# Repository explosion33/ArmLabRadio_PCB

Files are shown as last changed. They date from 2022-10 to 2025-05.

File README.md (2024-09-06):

# ArmLabRadio_PCB
KiCad files for CC1200 and STM32 based 2m / 70cm radio

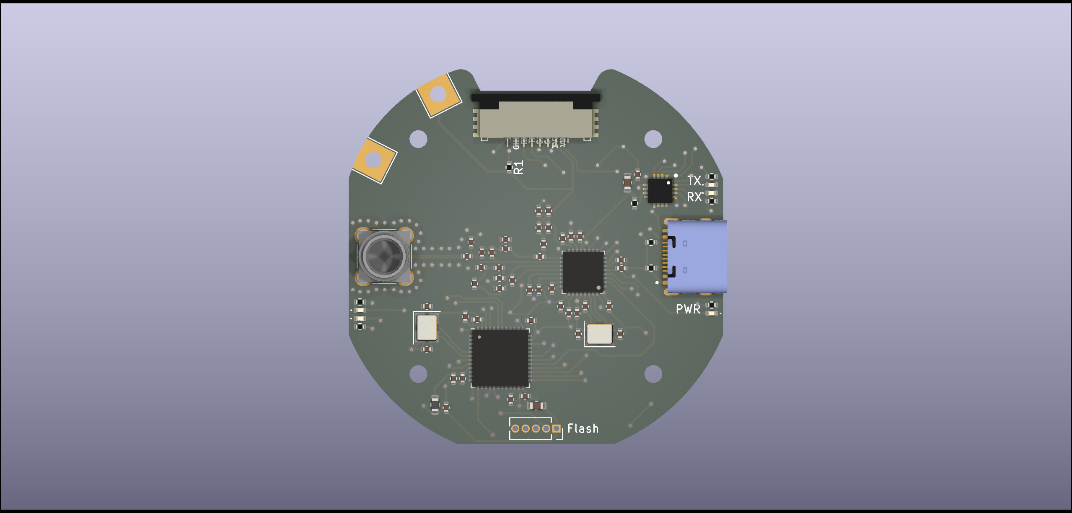
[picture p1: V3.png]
v3


## Software
This is the hardware repo for the project, checkout

[CC1200stm32](https://github.com/explosion33/CC1200stm32) for the embedded device code

[ArmLabCC1200](https://github.com/explosion33/ArmLabCC1200) for Serial / I2C inteface libraries

## Other
checkout

[RGRadioAPI](https://github.com/explosion33/RGRadioApi) for an example use case

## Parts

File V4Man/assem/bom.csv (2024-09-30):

Comment | Designator | Footprint | LCSC Part #
4.7uF Unpolarized capacitor | C1 | C_0603_1608Metric | C71631
10uF Unpolarized capacitor | C2 | C_0603_1608Metric | c
10pF Unpolarized capacitor | C3,C6,C31,C36 | C_0402_1005Metric | C32949
100nF Unpolarized capacitor | C4,C5,C7,C8,C13 | C_0402_1005Metric | C307331
2.2uF Unpolarized capacitor | C9 | C_0402_1005Metric | C12530
10nF Unpolarized capacitor | C10,C14,C20,C22,C42 | C_0402_1005Metric | C15195
1uF Unpolarized capacitor | C11,C12,C40 | C_0402_1005Metric | C52923
47nF Unpolarized capacitor | C15,C17,C18,C19,C23,C24,C25,C28,C29 | C_0402_1005Metric | C508865
0.22 uF Unpolarized capacitor | C16 | C_0402_1005Metric | C16772
1.8nF Unpolarized capacitor | C21 | C_0402_1005Metric | C162192
56pF Unpolarized capacitor | C26 | C_0402_1005Metric | C335543
100pF Unpolarized capacitor | C27 | C_0402_1005Metric | C126492
39pF Unpolarized capacitor | C30 | C_0402_1005Metric | C86288
5.1pF Unpolarized capacitor | C32,C33,C35 | C_0402_1005Metric | C281761
2.2pF Unpolarized capacitor | C34 | C_0402_1005Metric | C159806
6.2pF Unpolarized capacitor | C37 | C_0402_1005Metric | C325456
220pF Unpolarized capacitor | C38,C39 | C_0402_1005Metric | C363516
1nF Unpolarized capacitor | C41 | C_0402_1005Metric | C189467
220uF Unpolarized capacitor | C43 | C_1206_3216Metric | C528968
10uF Unpolarized capacitor | C44 | C_0402_1005Metric | C52923
100uF Unpolarized capacitor | C45 | C_0805_2012Metric | C141660
330uF Unpolarized capacitor | C46 | CP_Elec_10x10.5 | C5162354
22uF Unpolarized capacitor | C47,C48 | C_0805_2012Metric | C5674
PWR_LED Light emitting diode | D1 | LED_0402_1005Metric | C5160717
LED Light emitting diode | D2,D3 | LED_0402_1005Metric | C130722
TXT Light emitting diode | D4 | LED_0402_1005Metric | C136765
RXT Light emitting diode | D5 | LED_0402_1005Metric | C130722
SS34 40V 3A Schottky Diode, SMA | D6 | D_SMA | C3032484
EXT1 Generic connector, single row, 01x08, script generated (kicad-library-utils/schlib/autogen/connector/) | EX1 | Molex_200528-0080_1x08-1MP_P1.00mm_Horizontal | C132510
120R Ferrite bead, small symbol | FB1 | L_0603_1608Metric | C85831
MountingHole Mounting Hole without connection | H1,H2,H3,H4 | MountingHole_2.2mm_M2
TYPE-C-31-M-12 | J1 | HRO_TYPE-C-31-M-12 | C165948
PWR Generic connector, single row, 01x01, script generated (kicad-library-utils/schlib/autogen/connector/) | J2,J4 | TestPoint_THTPad_4.0x4.0mm_Drill2.0mm
GND Generic connector, single row, 01x01, script generated (kicad-library-utils/schlib/autogen/connector/) | J3,J5 | TestPoint_THTPad_4.0x4.0mm_Drill2.0mm
Conn_01x03_Pin Generic connector, single row, 01x03, script generated | J6 | PinHeader_1x03_P2.54mm_Vertical
56nH Inductor symbol for simulation only | L1,L2 | C_0402_1005Metric | C167484
27nH Inductor symbol for simulation only | L3,L4 | C_0402_1005Metric | C12669
15nH Inductor symbol for simulation only | L5,L6 | C_0402_1005Metric | C27143
22nH Inductor symbol for simulation only | L7 | C_0402_1005Metric | C12670
220uH Inductor | L8 | L_Sunlord_SWRB1207S | C182174
AntMount Generic connector, single row, 01x01, script generated (kicad-library-utils/schlib/autogen/connector/) | P1 | SMA_Amphenol_132134-11_Vertical | C504007
5.11k Resistor | R1,R3,R4,R12 | R_0402_1005Metric | C25906
0 Resistor, small US symbol | R2 | C_0402_1005Metric | C138289
1k Resistor | R5,R6,R7,R10,R11,R14,R15,R18 | R_0402_1005Metric | C11702
56k Resistor, small US symbol | R8 | C_0402_1005Metric | C25796
18k Resistor, small US symbol | R9 | C_0402_1005Metric | C25084
0R Resistor, small US symbol | R13 | C_0402_1005Metric | C138289
1.8k Resistor | R16 | R_0402_1005Metric | C170383
3.9k Resistor | R17 | R_0402_1005Metric | C413091
FLASH Generic connector, single row, 01x06, script generated (kicad-library-utils/schlib/autogen/connector/) | SWD1 | PinSocket_1x05_P2.54mm_Vertical
STM32F401CCU6 ARM Cortex-M4 MCU, 256KB flash, 64KB RAM, 84MHz, 1.7-3.6V, 36 GPIO, UFQFPN-48 | U1 | QFN-48-1EP_7x7mm_P0.5mm_EP5.6x5.6mm | C79861
CP2102N-Axx-xQFN20 USB to UART master bridge, QFN-20 | U2 | WFQFN-20 | C969913
CC1200 Low-Power, High-Performance RF Transceiver, QFN-32 | U3 | QFN-32-1EP_5x5mm_P0.5mm_EP3.45x3.45mm | C122881
SKY65366-21 | U4 | SKY65366-21_SKY
LM2576S 3.3V, 3A SIMPLE SWITCHER® Step-Down Voltage Regulator, TO-263 | U5 | TO-263-5_TabPin3 | C347415
AMS1117-3.3 1A Low Dropout regulator, positive, 3.3V fixed output, SOT-223 | U6 | SOT-223-3_TabPin2 | C6186
40MHz Four pin crystal, GND on pins 2 and 4 | X1 | Oscillator_SMD_Abracon_ASE-4Pin_3.2x2.5mm | C9010
16MHz Four pin crystal, GND on pins 2 and 4 | Y1 | Crystal_SMD_3225-4Pin_3.2x2.5mm | C13738

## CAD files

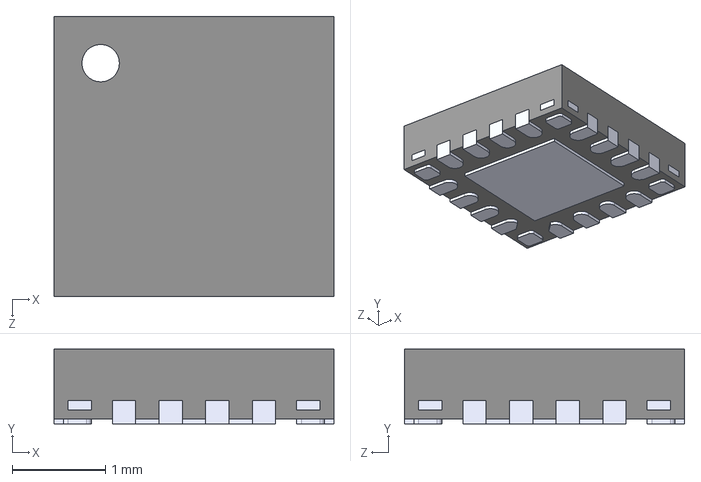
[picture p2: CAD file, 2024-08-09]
CP2102/CP2102N-A02-GQFN20.step
3.00 x 0.8 x 3.00 mm

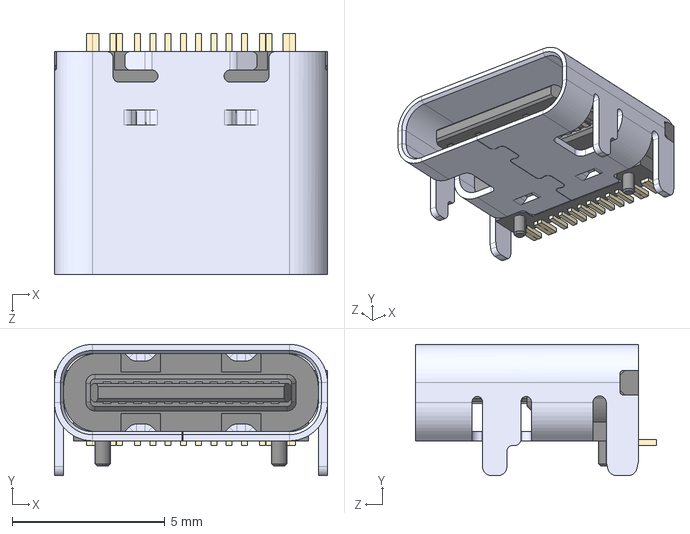
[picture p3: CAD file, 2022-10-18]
usbc/TYPE-C-31-M-12.step
8.94 x 4.30 x 7.90 mm

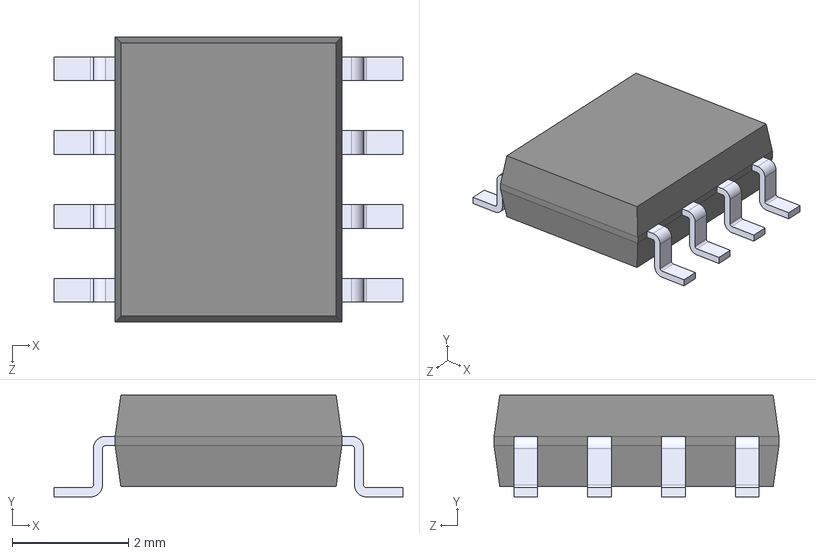
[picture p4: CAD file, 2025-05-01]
MCP41010/MCP41010-I_SN.step
6.00 x 1.75 x 4.90 mm

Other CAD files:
CP2102/cp2102n-a02-gqfn20.obj

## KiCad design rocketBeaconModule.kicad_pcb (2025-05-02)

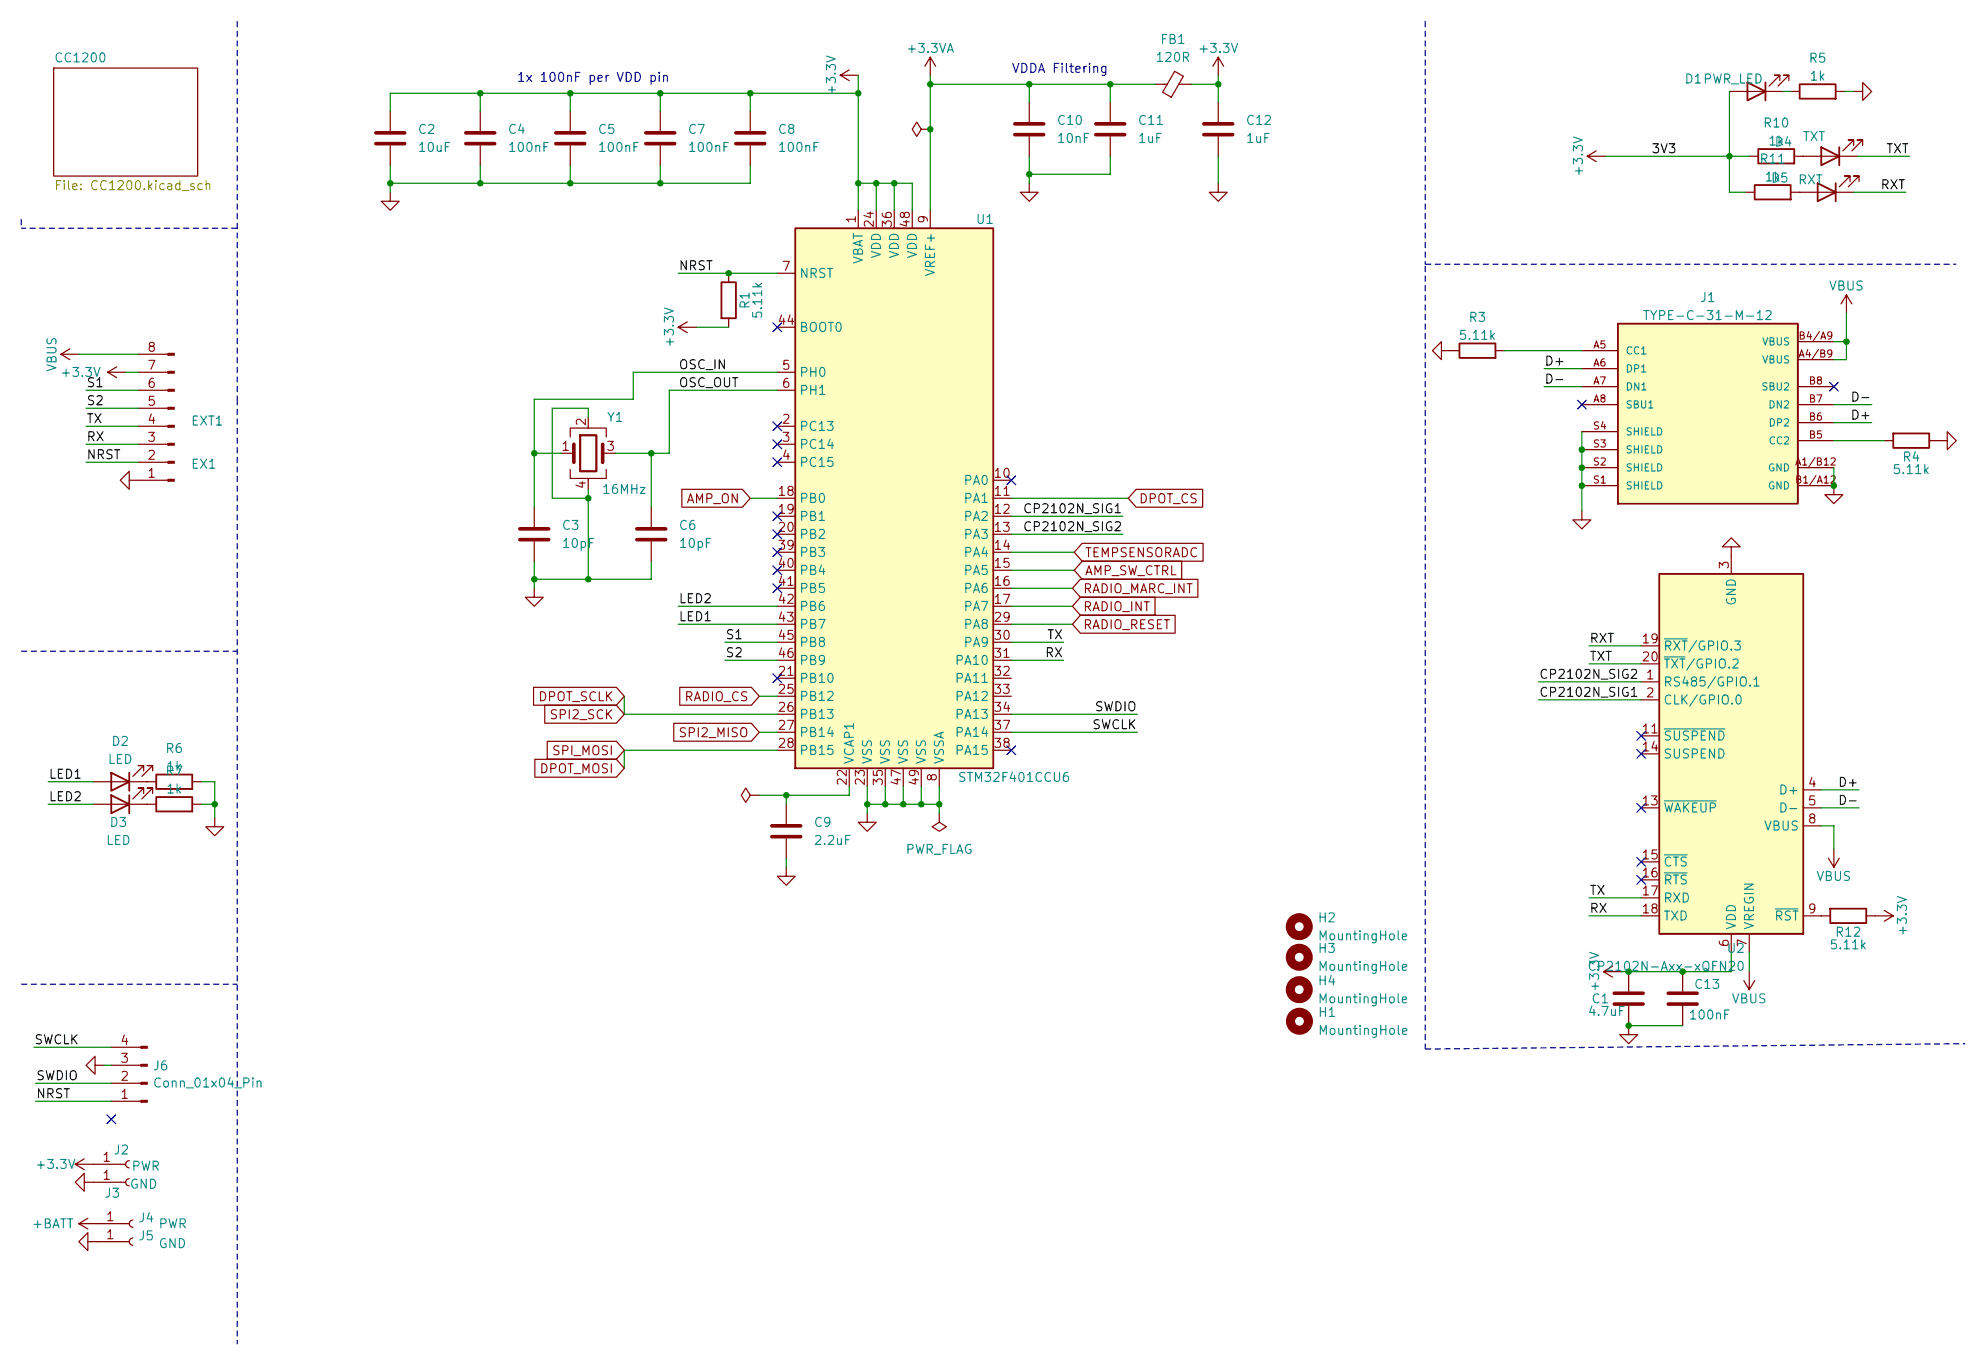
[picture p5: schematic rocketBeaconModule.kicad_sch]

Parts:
C1: 4.7uF; C_0603_1608Metric; LCSC Part C71631
C2: 10uF; C_0603_1608Metric; LCSC Part C19702
C3, C6: 10pF; C_0402_1005Metric; LCSC Part C32949
C4, C5, C7, C8, C13: 100nF; C_0402_1005Metric; LCSC Part C307331
C9: 2.2uF; C_0402_1005Metric; LCSC Part C12530
C10: 10nF; C_0402_1005Metric; LCSC Part C15195
C11, C12: 1uF; C_0402_1005Metric; LCSC Part C52923
D1: PWR_LED; LED_0402_1005Metric; LCSC Part C5160717
D2: LED; LED_0402_1005Metric; LCSC Part C131223
D3: LED; LED_0402_1005Metric; LCSC Part C130722
D4: TXT; LED_0402_1005Metric; LCSC Part C136765
D5: RXT; LED_0402_1005Metric; LCSC Part C130722
EX1: EXT1; Molex_200528-0080_1x08-1MP_P1.00mm_Horizontal; LCSC Part C132510
FB1: 120R; L_0603_1608Metric; LCSC Part C85831
H1, H2, H3, H4: MountingHole; MountingHole_2.2mm_M2
J1: TYPE-C-31-M-12; HRO_TYPE-C-31-M-12; PARTREV 2020.12.08; LCSC Part C165948
J2, J4: PWR; TestPoint_THTPad_4.0x4.0mm_Drill2.0mm
J3, J5: GND; TestPoint_THTPad_4.0x4.0mm_Drill2.0mm
J6: Conn_01x04_Pin; PinHeader_1x04_P2.54mm_Vertical
R1, R3, R4, R12: 5.11k; R_0402_1005Metric; LCSC Part C25906
R5, R6, R7, R10, R11: 1k; R_0402_1005Metric; LCSC Part C11702
U1: STM32F401CCU6; QFN-48-1EP_7x7mm_P0.5mm_EP5.6x5.6mm; LCSC Part C79861
U2: CP2102N-Axx-xQFN20; WFQFN-20; LCSC Part C969913
Y1: 16MHz; Crystal_SMD_3225-4Pin_3.2x2.5mm; LCSC Part C13738

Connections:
+3.3V: C1.1, C2.1, C4.1, C5.1, C7.1, C8.1, C12.1, C13.1, D1.2 (A), EX1.7, FB1.2, J2.1, R1.2, R10.1, R11.1, R12.1, U1.1 (VBAT), U1.24 (VDD), U1.36 (VDD), U1.48 (VDD), U2.6 (VDD); also elsewhere on the board
+3.3VA: C10.1, C11.1, FB1.1, U1.9 (VREF+)
+BATT: J4.1; also elsewhere on the board
/CP2102N_SIG1: U1.12 (PA2), U2.2 (CLK/GPIO.0)
/CP2102N_SIG2: U1.13 (PA3), U2.1 (RS485/GPIO.1)
/D+: J1.A6 (DP1), J1.B6 (DP2), U2.4 (D+)
/D-: J1.A7 (DN1), J1.B7 (DN2), U2.5 (D-)
/LED1: D2.2 (A), U1.43 (PB7)
/LED2: D3.2 (A), U1.42 (PB6)
/NRST: EX1.2, J6.1, R1.1, U1.7 (NRST)
/OSC_IN: C3.1, U1.5 (PH0), Y1.1
/OSC_OUT: C6.1, U1.6 (PH1), Y1.3
/RX: EX1.3, U1.31 (PA10), U2.18 (TXD)
/RXT: D5.1 (K), U2.19 (~RXT/GPIO.3)
/S1: EX1.6, U1.45 (PB8)
/S2: EX1.5, U1.46 (PB9)
/SWCLK: J6.4, U1.37 (PA14)
/SWDIO: J6.2, U1.34 (PA13)
/TX: EX1.4, U1.30 (PA9), U2.17 (RXD)
/TXT: D4.1 (K), U2.20 (~TXT/GPIO.2)
AMP_ON: U1.18 (PB0); also elsewhere on the board
AMP_SW_CTRL: U1.15 (PA5); also elsewhere on the board
DPOT_CS: U1.11 (PA1); also elsewhere on the board
DPOT_MOSI: U1.28 (PB15); also elsewhere on the board
DPOT_SCLK: U1.26 (PB13); also elsewhere on the board
GND: C1.2, C2.2, C3.2, C4.2, C5.2, C6.2, C7.2, C8.2, C9.2, C10.2, C11.2, C12.2, C13.2, EX1.1, J1.A1/B12 (GND), J1.B1/A12 (GND), J1.S1 (SHIELD), J1.S2 (SHIELD), J1.S3 (SHIELD), J1.S4 (SHIELD), J3.1, J5.1, J6.3, R3.1, R4.1, R5.2, R6.2, R7.2, U1.8 (VSSA), U1.23 (VSS), U1.35 (VSS), U1.47 (VSS), U1.49 (VSS), U2.3 (GND), U2.12 (GND), Y1.2, Y1.4; also elsewhere on the board
unnamed: D1.1 (K), R5.1
unnamed: D2.1 (K), R6.1
unnamed: D3.1 (K), R7.1
unnamed: D4.2 (A), R10.2
unnamed: D5.2 (A), R11.2
unnamed: J1.A5 (CC1), R3.2
unnamed: J1.B5 (CC2), R4.2
unnamed: C9.1, U1.22 (VCAP1)
unnamed: R12.2, U2.9 (~RST)
RADIO_CS: U1.25 (PB12); also elsewhere on the board
RADIO_INT: U1.17 (PA7); also elsewhere on the board
RADIO_MARC_INT: U1.16 (PA6); also elsewhere on the board
RADIO_RESET: U1.29 (PA8); also elsewhere on the board
SPI2_MISO: U1.27 (PB14); also elsewhere on the board
TEMPSENSORADC: U1.14 (PA4); also elsewhere on the board
VBUS: EX1.8, J1.A4/B9 (VBUS), J1.B4/A9 (VBUS), U2.7 (VREGIN), U2.8 (VBUS)

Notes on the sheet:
VDDA Filtering
1x 100nF per VDD pin

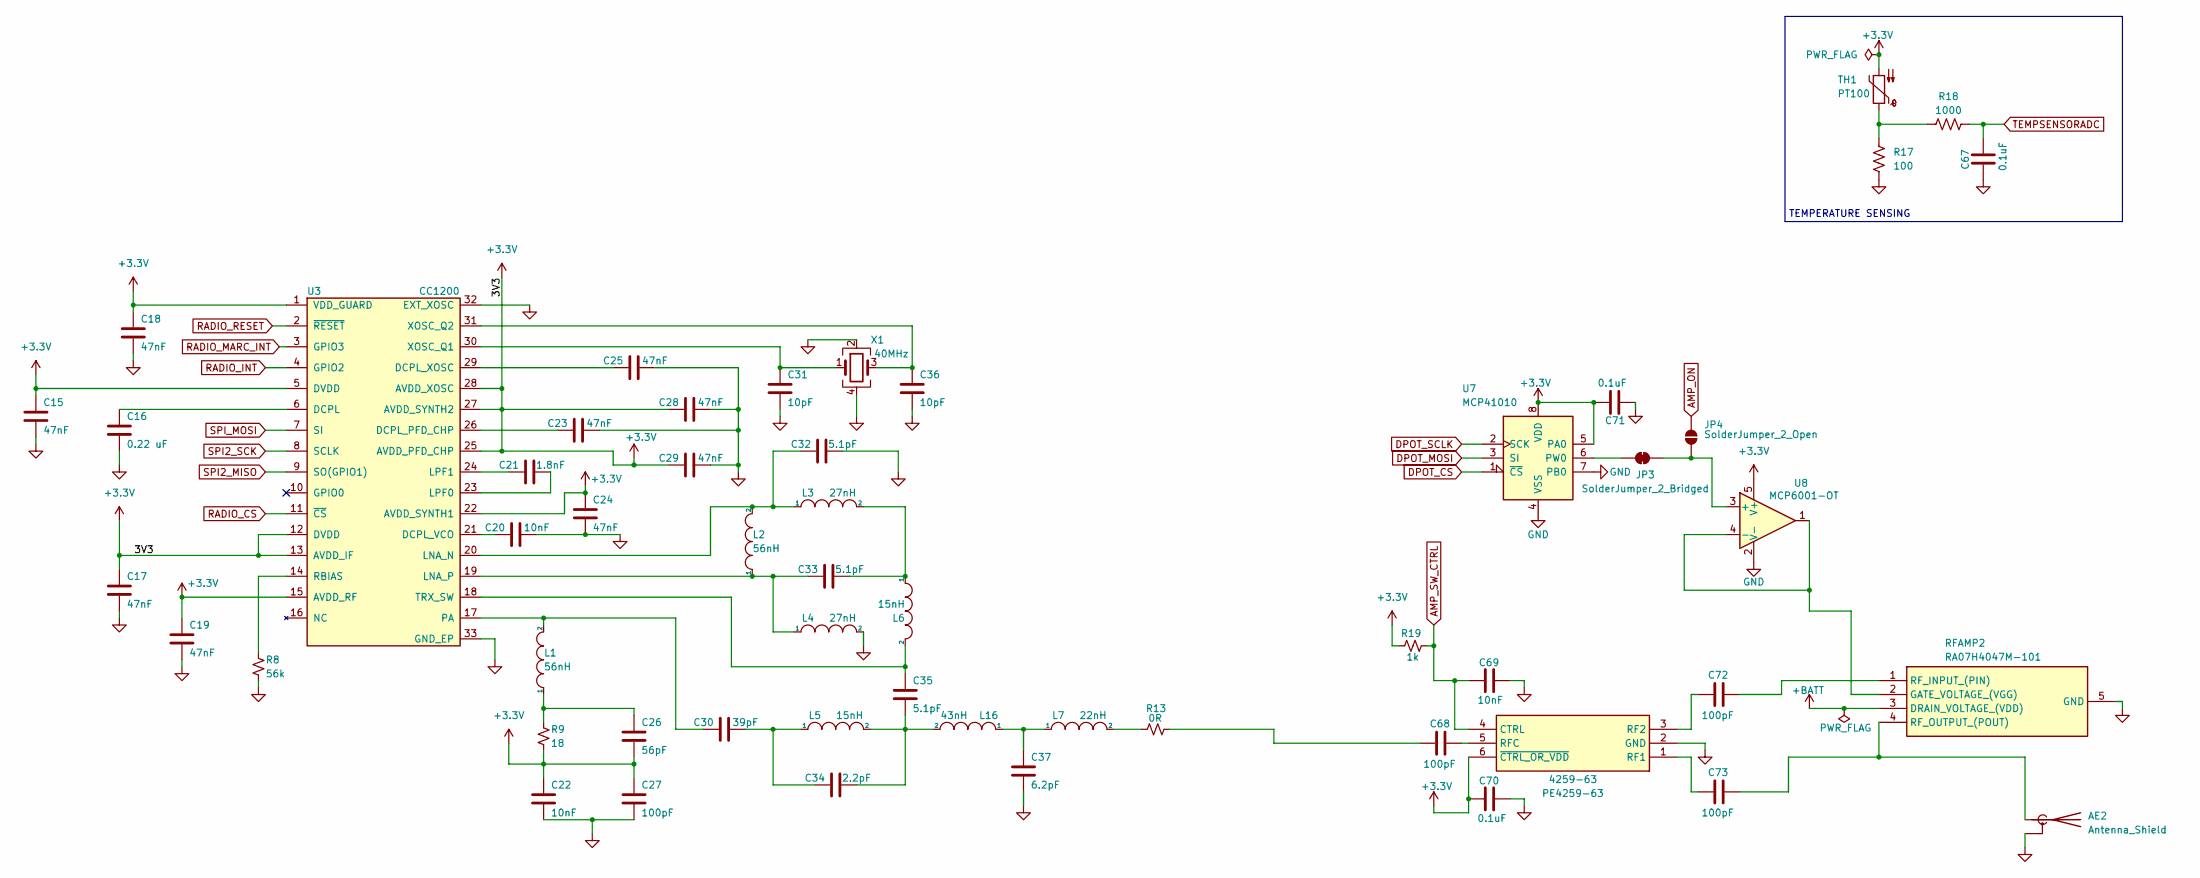
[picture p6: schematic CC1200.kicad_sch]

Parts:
AE2: Antenna_Shield; SMA_Amphenol_132134-11_Vertical; LCSC Part C496549
C15, C17, C18, C19, C23, C24, C25, C28, C29: 47nF; C_0402_1005Metric; LCSC Part C508865
C16: 0.22 uF; C_0402_1005Metric; LCSC Part C16772
C20, C22: 10nF; C_0402_1005Metric; LCSC Part C15195
C21: 1.8nF; C_0402_1005Metric; LCSC Part C162192
C26: 56pF; C_0402_1005Metric; LCSC Part C335543
C27: 100pF; C_0402_1005Metric; LCSC Part C126492
C30: 39pF; C_0402_1005Metric; LCSC Part C86288
C31, C36: 10pF; C_0402_1005Metric; LCSC Part C32949
C32, C33, C35: 5.1pF; C_0402_1005Metric; LCSC Part C281761
C34: 2.2pF; C_0402_1005Metric; LCSC Part C159806
C37: 6.2pF; C_0402_1005Metric; LCSC Part C325456
C67, C71: 0.1uF; C_0402_1005Metric; LCSC Part C1525
C68, C72, C73: 100pF; C_0402_1005Metric; LCSC C1546
C69: 10nF; C_0402_1005Metric; LCSC C15195
C70: 0.1uF; C_0402_1005Metric; LCSC C1525
JP3: SolderJumper_2_Bridged; SolderJumper-2_P1.3mm_Bridged_RoundedPad1.0x1.5mm
JP4: SolderJumper_2_Open; SolderJumper-2_P1.3mm_Open_RoundedPad1.0x1.5mm
L1, L2: 56nH; C_0402_1005Metric; LCSC Part C167484
L3, L4: 27nH; C_0402_1005Metric; LCSC Part C12669
L5, L6: 15nH; C_0402_1005Metric; LCSC Part C27143
L7: 22nH; C_0402_1005Metric; LCSC Part C12670
L16: 43nH; L_0402_1005Metric; LCSC Part C167478
PE4259-63: 4259-63; SOT-363_SC-70-6; Manufacturer_Part_Number 4259-63; LCSC Part C470892
R8: 56k; C_0402_1005Metric; LCSC Part C25796
R9: 18; R_0402_1005Metric; LCSC Part C25084
R13: 0R; C_0402_1005Metric; LCSC Part C138289
R17: 100; R_0402_1005Metric; LCSC Part C25076
R18: 1000; R_0402_1005Metric; LCSC Part C21190
R19: 1k; R_0402_1005Metric; LCSC C11702
RFAMP2: RA07H4047M-101; RA07h4047M; Manufacturer_Part_Number RA07H4047M-101
TH1: PT100; R_0603_1608Metric; LCSC Part C141518
U3: CC1200; QFN-32-1EP_5x5mm_P0.5mm_EP3.45x3.45mm; LCSC Part C122881
U7: MCP41010; SOIC127P599X175-8N; LCSC Part C136395
U8: MCP6001-OT; SOT-23-5; LCSC Part C116490
X1: 40MHz; Oscillator_SMD_Abracon_ASE-4Pin_3.2x2.5mm; LCSC Part C9010

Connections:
+3.3V: C15.1, C17.1, C18.1, C19.1, C22.1, C24.1, C26.2, C27.1, C28.2, C29.2, C70.2, C71.1, PE4259-63.6 (~CTRL_OR_VDD), R9.2, R19.2, TH1.2, U3.1 (VDD_GUARD), U3.5 (DVDD), U3.12 (DVDD), U3.13 (AVDD_IF), U3.15 (AVDD_RF), U3.22 (AVDD_SYNTH1), U3.25 (AVDD_PFD_CHP), U3.27 (AVDD_SYNTH2), U3.28 (AVDD_XOSC), U7.5 (PA0), U7.8 (VDD), U8.5 (V+); also elsewhere on the board
+BATT: RFAMP2.3 (DRAIN_VOLTAGE_(VDD)); also elsewhere on the board
AMP_ON: JP4.2 (B); also elsewhere on the board
AMP_SW_CTRL: C69.2, PE4259-63.4 (CTRL), R19.1; also elsewhere on the board
DPOT_CS: U7.1 (~CS); also elsewhere on the board
DPOT_MOSI: U3.7 (SI), U7.3 (SI); also elsewhere on the board
DPOT_SCLK: U3.8 (SCLK), U7.2 (SCK); also elsewhere on the board
GND: AE2.2 (Shield), C15.2, C16.2, C17.2, C18.2, C19.2, C20.1, C22.2, C23.1, C24.2, C25.1, C27.2, C28.1, C29.1, C31.2, C32.1, C36.2, C37.2, C67.2, C69.1, C70.1, C71.2, L4.2, PE4259-63.2 (GND), R8.2, R17.2, RFAMP2.5 (GND), U3.32 (EXT_XOSC), U3.33 (GND_EP), U7.4 (VSS), U7.7 (PB0), U8.2 (V-), X1.2, X1.4; also elsewhere on the board
unnamed: AE2.1 (A), C73.2, RFAMP2.4 (RF_OUTPUT_(POUT))
unnamed: C26.1, L1.1, R9.1
unnamed: C30.1, C34.2, L5.1
unnamed: C33.1, L3.2, L6.1
unnamed: C34.1, C35.2, L5.2, L16.2
unnamed: C37.1, L7.1, L16.1
unnamed: C68.1, R13.2
unnamed: JP3.1 (A), U7.6 (PW0)
unnamed: JP3.2 (B), JP4.1 (A), U8.3 (+)
unnamed: L7.2, R13.1
unnamed: C73.1, PE4259-63.1 (RF1)
unnamed: C72.1, PE4259-63.3 (RF2)
unnamed: C68.2, PE4259-63.5 (RFC)
unnamed: R17.1, R18.1, TH1.1
unnamed: RFAMP2.2 (GATE_VOLTAGE_(VGG)), U8.1, U8.4 (-)
unnamed: C72.2, RFAMP2.1 (RF_INPUT_(PIN))
unnamed: C16.1, U3.6 (DCPL)
unnamed: C23.2, U3.26 (DCPL_PFD_CHP)
unnamed: C20.2, U3.21 (DCPL_VCO)
unnamed: C25.2, U3.29 (DCPL_XOSC)
unnamed: C32.2, L2.2, L3.1, U3.20 (LNA_N)
unnamed: C33.2, L2.1, L4.1, U3.19 (LNA_P)
unnamed: C21.1, U3.23 (LPF0)
unnamed: C21.2, U3.24 (LPF1)
unnamed: C30.2, L1.2, U3.17 (PA)
unnamed: R8.1, U3.14 (RBIAS)
unnamed: C35.1, L6.2, U3.18 (TRX_SW)
unnamed: C31.1, U3.30 (XOSC_Q1), X1.1
unnamed: C36.1, U3.31 (XOSC_Q2), X1.3
RADIO_CS: U3.11 (~CS); also elsewhere on the board
RADIO_INT: U3.4 (GPIO2); also elsewhere on the board
RADIO_MARC_INT: U3.3 (GPIO3); also elsewhere on the board
RADIO_RESET: U3.2 (~RESET); also elsewhere on the board
SPI2_MISO: U3.9 (SO(GPIO1)); also elsewhere on the board
TEMPSENSORADC: C67.1, R18.2; also elsewhere on the board

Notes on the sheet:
TEMPERATURE SENSING

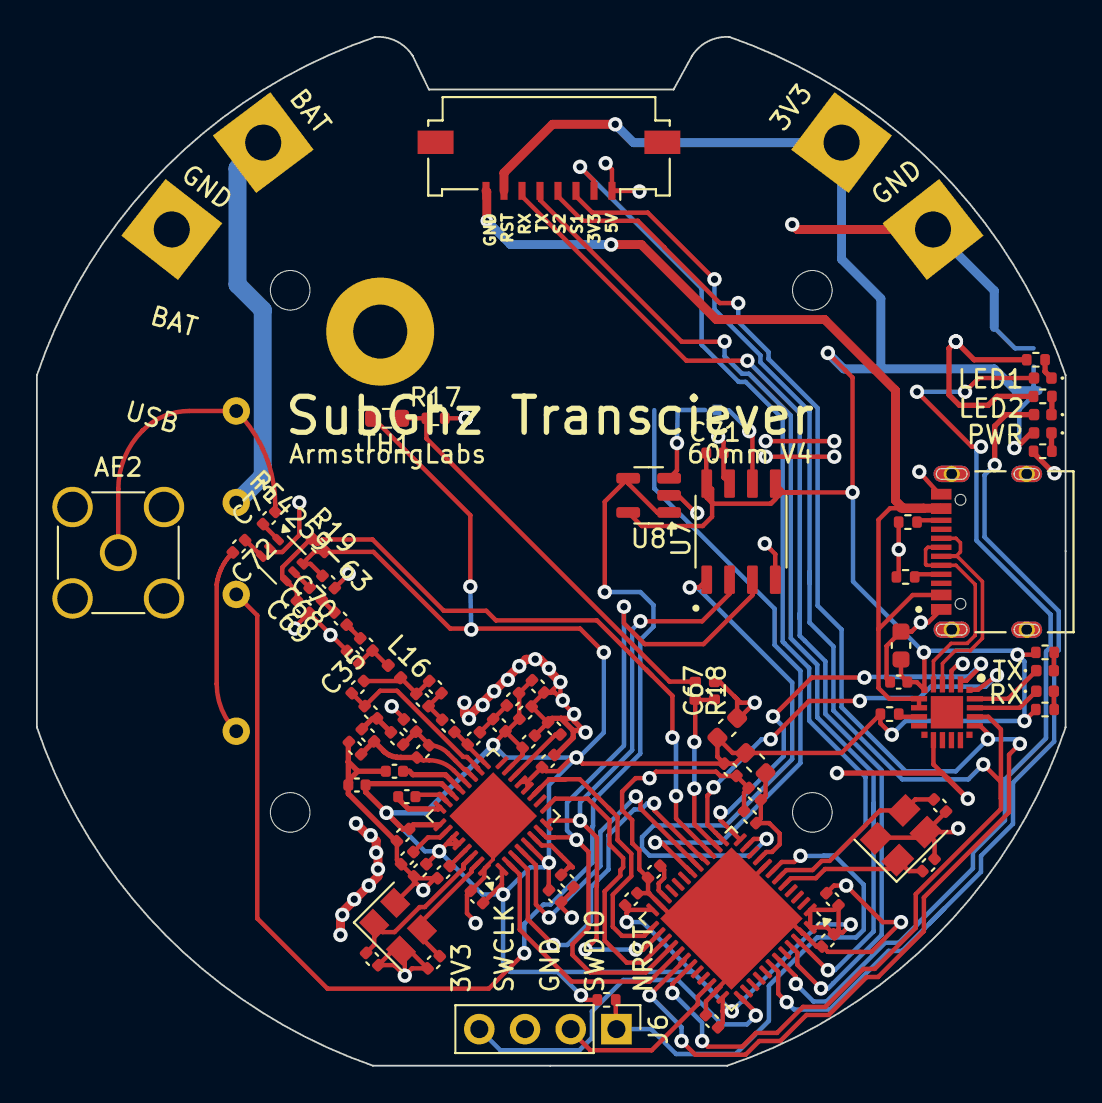
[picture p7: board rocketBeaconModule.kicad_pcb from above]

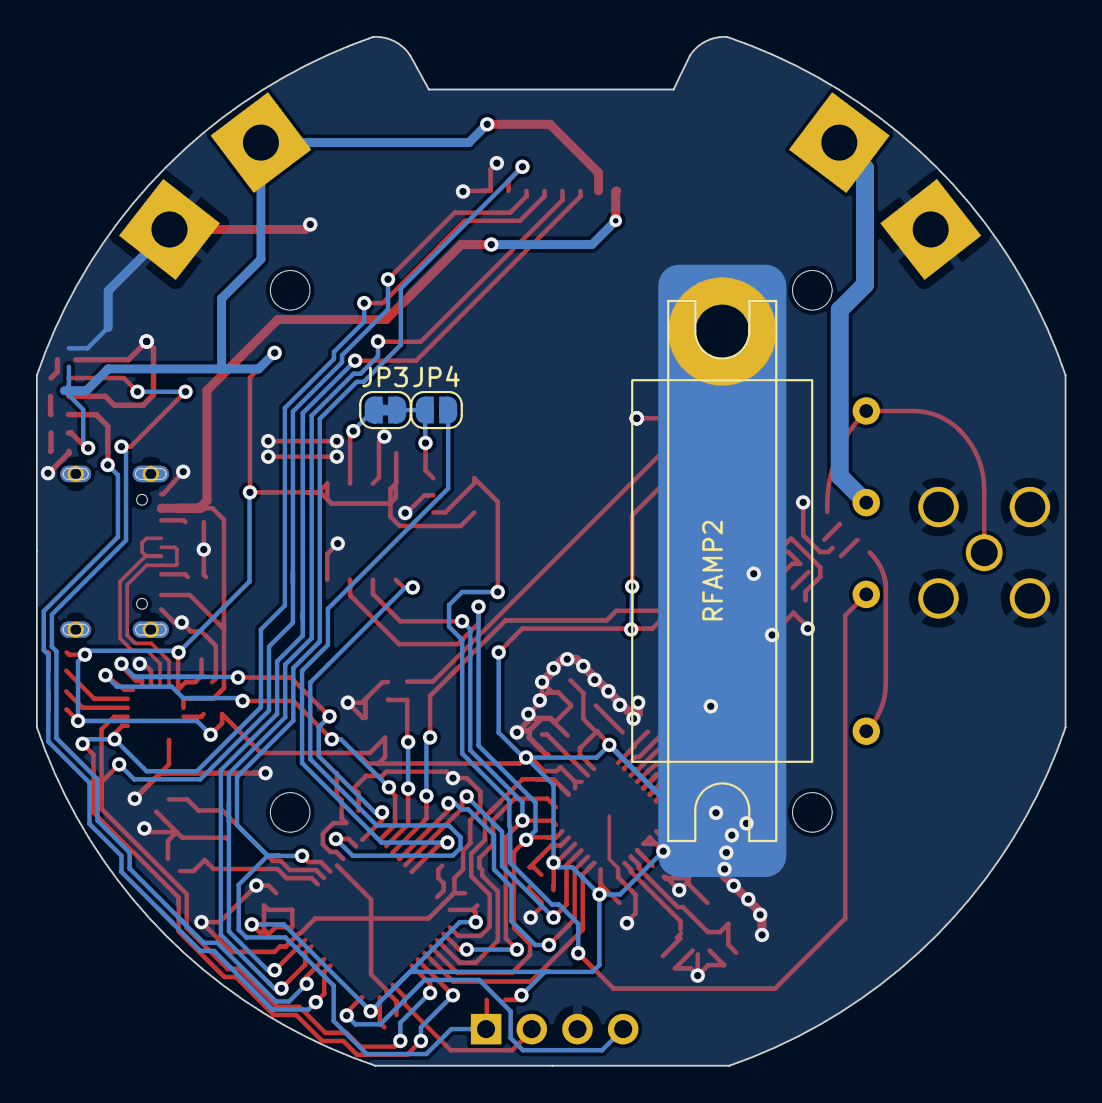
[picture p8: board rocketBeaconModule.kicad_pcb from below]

Board: 2 copper layers, 57.2 x 57.2 mm, 96 parts (5 on the bottom side), 71 nets.

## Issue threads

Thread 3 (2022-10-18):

USB C Grounding

Llibyddap, 2022-10-18:
The USB C housing isn't currently grounded to anything.  Need to figure out if it should be grounded to the rocket housing (?) or to the common PBC ground plain.  Would this affect anything other than PCB data communications (UART?) see: https://electronics.stackexchange.com/questions/422271/direct-connection-of-uart-serial-port-to-usb-type-c

Closed 2022-10-19.

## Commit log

2022-10-18 Initial radiobeacon designs
    [629105150521 (rev1).stp, CC1200.kicad_sch, TYPE-C-31-M-12.step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]
2022-10-19 fixed usb / io footprint mixup
    [rocketBeaconModule.kicad_pcb, rocketBeaconModule.kicad_sch]
2022-10-19 removed old footprints and replaced with new ones
    [rocketBeaconModule.kicad_pcb, rocketBeaconModule.kicad_sch]
2022-10-19 DRC resolution on PCB layouts
    [rocketBeaconModule.kicad_pcb]
2022-10-19 updated silk screen\nincreased spacing between leds\nchanged version number to 2.0
    [rocketBeaconModule.kicad_pcb]
2022-10-19 Set Version 1.1
    [rocketBeaconModule.kicad_pcb]
2022-10-19 backup v1.1; add part numbers
    [629105150521 (rev1).stp, CC1200.kicad_sch, bom.csv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]
2024-08-09 V3 changes
    [629105150521 (rev1).stp, CC1200.kicad_sch, CP2102N-A02-GQFN20.step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]
2024-08-09 added power pads
    [rocketBeaconModule.kicad_pcb, rocketBeaconModule.kicad_sch]
2024-09-06 Added larger 60mm cutout to match rocket club *note this is not nescesary since mounting holes line up between both sizes, it would be purely aesthetic
    [rocketBeaconModule.kicad_pcb]
2024-09-30 V4 Changes Added SKYWORKS +30db 4W FEM Added LM2576 3.9V supply Increased diameter to 60mm Re-routed full board
    [CC1200.kicad_sch, rocketBeaconModule.kicad_pcb, rocketBeaconModule.kicad_sch]
2024-09-30 Adjusted some component footprints and part numbers Increased size of inductor and repositioned generated gbrs, drills, bom and cpl (up to date)
    [CC1200.kicad_sch, bom.csv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]
2024-11-14 switched pins on ribbon cable to connect evenly with FC when flipped
    [rocketBeaconModule.kicad_pcb, rocketBeaconModule.kicad_sch]
2025-04-26 removed old PA
    [CC1200.kicad_sch, rocketBeaconModule.kicad_pcb, rocketBeaconModule.kicad_sch]
2025-04-27 checked matching network on CC1200 schematic
    [CC1200.kicad_sch, rocketBeaconModule.kicad_sch]
2025-04-28 completed most of radio schematic
    [CC1200.kicad_sch, SKY13351-378LF.step, rocketBeaconModule.kicad_sch]
2025-04-28 changed rf switch, updated rf amp footprint and updated schematic
    [4259-63.stp, CC1200.kicad_sch, rocketBeaconModule.kicad_pcb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]
2025-04-30 fixed temp sensor and updated digpot stm32 connections
    [CC1200.kicad_sch, rocketBeaconModule.kicad_sch]
2025-04-30 added decoupling capacitor to dpot and changed RTD1000 to RTD100
    [CC1200.kicad_sch]
2025-04-30 reference/backup for mostly routed pcb
    [CC1200.kicad_sch, CONSMA002-SMD-G--3DModel-STEP-56544.STEP, MCP41010-I_SN.step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]
2025-04-30 finished majority of routing other than matching network and amplifier/switch/antenna
    [rocketBeaconModule.kicad_pcb]
2025-05-01 finished routing pcb and passed DRC, waiting for review by Ethan
    [CC1200.kicad_sch, rocketBeaconModule.kicad_pcb, rocketBeaconModule.kicad_sch]
2025-05-01 Revert "Stephen"
    [4259-63.stp, CC1200.kicad_sch, CONSMA002-SMD-G--3DModel-STEP-56544.STEP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]
2025-05-01 added Mitsibushi Amp w/ supporting gate control circuitry, switching, and temperature monitoring
    [CC1200.kicad_sch, MCP41010-I_SN.step, rocketBeaconModule.kicad_pcb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]
2025-05-02 BOM fixes and manufactureing files
    [CC1200.kicad_sch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]
